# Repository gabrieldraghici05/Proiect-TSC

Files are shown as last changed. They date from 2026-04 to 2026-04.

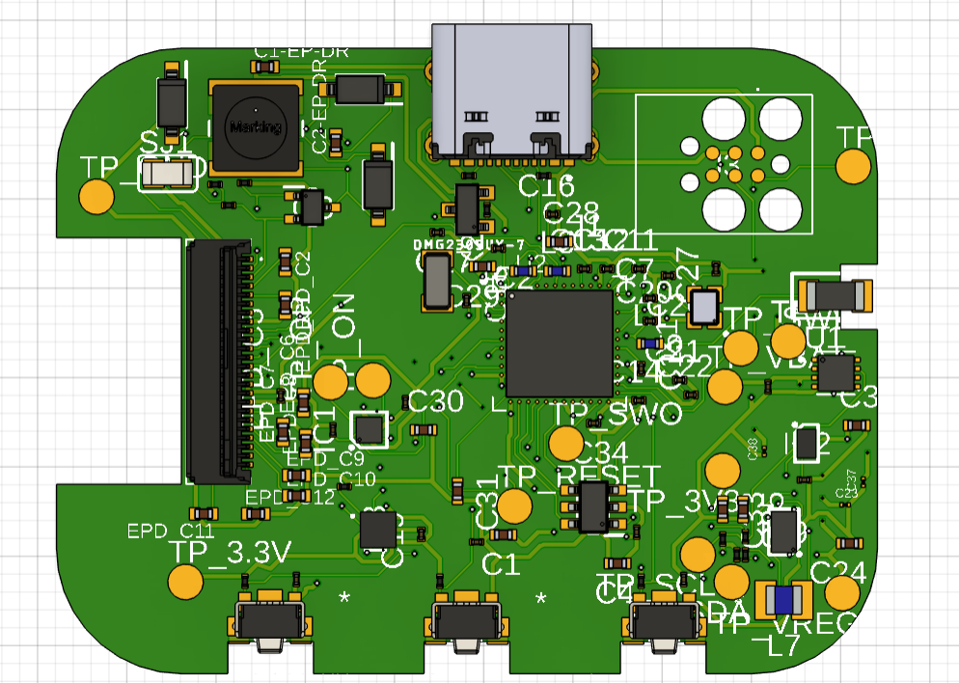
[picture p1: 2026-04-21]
Images/PCB 3D.png

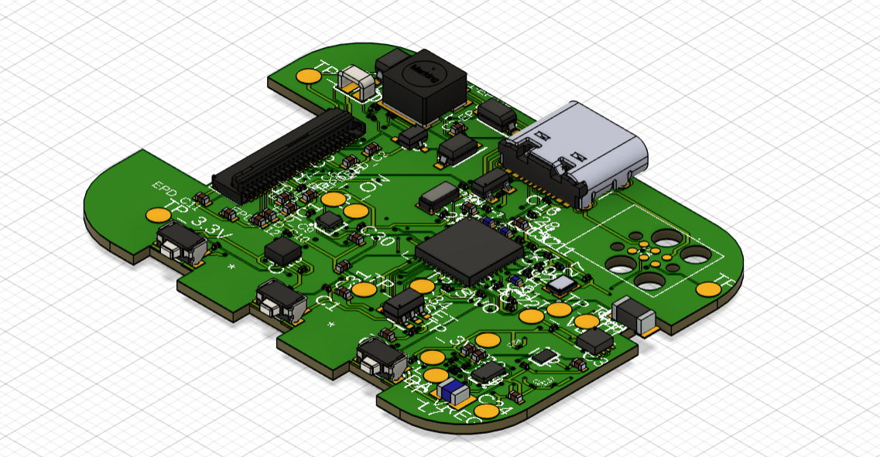
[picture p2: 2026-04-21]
Images/PCB 3D - 2.png

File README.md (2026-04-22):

# Proiect-TSC

## Descriere generală

InkTime este un smartwatch construit în jurul microcontroller-ului nRF52840, utilizând un afișaj E-Paper. Proiectul este dezvoltat în Autodesk Fusion: de la concepția schemelor și rutarea unui PCB pe 4 straturi, până la integrarea mecanică finală în carcasă.

Principalele caracteristici:
- Procesare: nRF52840 (Cortex-M4F) cu conectivitate Bluetooth 5.0 integrată
- Afișaj: Ecran E-Paper (SPI)
- Senzori: Accelerometru BMA423 pentru pedometru și gesturi
- Baterie LiPo cu circuit de încărcare dedicat (BQ25180).
- Regulator DC/DC (RT6160) pentru o tensiune stabilă de 3.3V
- Fuel Gauge (MAX17048) pentru monitorizarea nivelului bateriei
- Driver haptic (DRV2605) pentru feedback
- Conectivitate USB-C pentru încărcare
- 3 butoane fizice pentru interacțiune

---

## Diagrama bloc

```text
                         +-------------------+
                         |    Baterie LiPo   |
                         +--------+----------+
                                  |
                         +--------v----------+
                         |  LiPo Charger     |  <-- USB-C (5V / VBUS)
                         |  BQ25180YBGR      |
                         +--------+----------+
                                  | VBAT (3.7-4.2V)
                         +--------v----------+
                         |  Fuel Gauge       |  <-- I2C --> nRF52840
                         |  MAX17048G+T10    |
                         +--------+----------+
                                  |
                         +--------v----------+
                         |  DC/DC Regulator  |  <-- I2C --> nRF52840
                         |  RT6160AWSC       |
                         +--------+----------+
                                  | 3V3
          +-----------------------+-----------------------+
          |                       |                       |
+---------v---------+   +---------v---------+   +---------v---------+
|   nRF52840 (U1)   |   |  ESD Protection   |   |   Butoane (x3)    |
|   Microcontroller |   |  USBLC6-2SC6Y     |   |   EVP-AKE31A      |
+---------+---------+   +-------------------+   +-------------------+
          |
    +-----+------+------+------+
    |            |      |      |
+---v---+  +----v--+  +-v---+ +-v---------+
| SPI   |  |  I2C  |  | SWD | | GPIO/ANT  |
+---+---+  +---+---+  +-----+ +-----------+
    |          |
+---v---+   +--+--+--+--+
|E-Paper|   | IMU | Haptic|
|Display|   |BMA423|DRV2605|
+-------+   +-------+-----+
```

---
## Bill of Materials (BOM)

| Cantitate | Componenta | Descriere | Referinta | 
|:---:|:---:|:---:|:---:|
| 1 | nRF52840 | Microcontroller ARM Cortex-M4, BT 5.0 | U1 | 
| 1 | BQ25180YBGR | LiPo Charger IC, 8-DSBGA | IC1 | 
| 1 | DRV2605YZFR | Haptic Driver ERM/LRA, 9-BGA | IC2 |
| 1 | BMA423 | IMU Accelerometru triaxial 12-bit | IC3 |
| 1 | MAX17048G+T10 | Fuel Gauge 1-Cell ModelGauge | U3 | 
| 1 | RT6160AWSC | Buck-Boost DC/DC Regulator I2C, 15-WL-CSP | IC9 | 
| 1 | USBLC6-2SC6Y | ESD Protection TVS Diode, SOT-23-6 | D3 | 
| 1 | KH-TYPE-C-16P | Conector USB-C 16 pini | J4 |
| 1 | 503480-2400 | Conector FPC/FFC 0.5mm 24 circuite | J1 | 
| 1 | DMG2305UX-7 | P-Channel MOSFET 20V/4.2A SOT-23 | Q2 | 
| 1 | SI1308EDL-T1-GE3 | N-Channel MOSFET 30V/1.5A SC-70 | Q3 | 
| 3 | MBR0530 | Dioda Schottky 30V/500mA SOD-123 | D1, D2, D5 | 
| 3 | EVP-AKE31A | Buton tactil SMD ultra-subtire | SW_DN, SW_ENT, SW_UP | 
| 1 | 2450AT18B100E | Antena 2.45GHz SMD | ANT1 | 
| 1 | FTC252012SR47MBCA | Inductor SMD 0.47uH 2016 | L7 | 
| 1 | 744043680 | Inductor SMD 68uH WE-TPC | L5 |
| 1 | TC2030-IDC | Conector Tag-Connect 6 pini SWD | J2 |
| 1 | X1 (32MHz) | Crystal 32MHz 2016 SMD | X1 |
| 1 | X2 (32.768kHz) | Crystal 32.768kHz 3215 SMD | X2 | 
| ~50 | Condensatoare SMD | 0201/0402, diverse valori (1pF - 22uF) | Cx | 
| ~15 | Rezistoare SMD | 0201, diverse valori (2.2Ω - 10kΩ) | Rx |
| ~4 | Inductoare SMD | 0402, diverse valori (3.9nH - 15nH, 10uH) | Lx |
| 14 | Test Pad TP20R | Test pad-uri SMD 2mm | TP_* |
| 1 | Solder Jumper SJ | Jumper SMD | SJ1 |

---

## Funcționalitate hardware

#### Componente și roluri
Sistemul este coordonat de nRF52840, care gestionează atât logica internă, stările de sleep pentru economisirea energiei, cât și comunicarea Bluetooth.

* Alimentare și Power Management: Bateria Li-Po este conectată direct la test pad-urile plăcii pentru a economisi spațiu pe verticală. Încărcarea este gestionată de BQ25180. Tensiunea bateriei este monitorizată precis de Fuel Gauge-ul MAX17048, iar alimentarea componentelor logice la 3.3V este asigurată de convertorul DC/DC RT6160 (ales în detrimentul unui LDO pentru un randament energetic superior).

* Interfața cu utilizatorul: Afișajul E-Paper este controlat prin SPI pentru o viteză mare de transfer, consumând energie doar la actualizarea imaginii. Input-ul se face prin 3 butoane tactile cu debouncing software, iar feedback-ul este asigurat de driverul haptic DRV2605 conectat la un actuator de tip shaker.

* Senzori: Accelerometrul BMA423 este legat pe magistrala I2C și este folosit pentru funcții precum ridicarea mâinii pentru aprindere (wake-on-wrist).

#### Interfețe de comunicație
* I2C: LiPo Charger, DC/DC, IMU, Fuel Gauge, Haptic Driver. (Folosește rezistențe de pull-up externe pentru stabilitate).

* SPI: E-Paper Display Connector (viteză mare de transmisie a datelor grafice).

---

## Pinii nRF52840

| Pin nRF52840 | Semnal | Modul conectat | Interfata | Descriere |
| :--- | :--- | :--- | :--- | :--- |
| P0.02/AIN0 | SCK | E-Paper Display | SPI | Clock serial SPI |
| P0.03/AIN1 | MOSI | E-Paper Display | SPI | Date catre display (Master Out Slave In) |
| P0.05/AIN3 | CS | E-Paper Display | SPI | Chip Select display |
| P0.15 | EPD_RST | E-Paper Display | GPIO | Reset display |
| P0.16 | EPD_DC | E-Paper Display | GPIO | Data/Command select |
| P0.17 | EPD_BUSY | E-Paper Display | GPIO | Stare ocupata display |
| P0.06 | SCL | IMU, LiPo Charger, DC/DC, Fuel Gauge, Haptic | I2C | Clock linie I2C |
| P0.07 | SDA | IMU, LiPo Charger, DC/DC, Fuel Gauge, Haptic | I2C | Date linie I2C |
| P0.08 | IMU_INT2 | BMA423 | GPIO | Intrerupere 2 accelerometru |
| P1.08 | IMU_INT1 | BMA423 | GPIO | Intrerupere 1 accelerometru |
| P0.10/NFC2 | FUELGAUGE_ALT | MAX17048 | GPIO | Alarma nivel scazut baterie |
| P0.11 | CHARGER_PG | BQ25180 | GPIO | Semnal Power Good charger |
| P0.12 | HAPTIC_EN | DRV2605 | GPIO | Enable driver haptic |
| P0.13 | BTN_UP | SW_UP | GPIO | Buton sus |
| P0.14 | BTN_ENT | SW_ENT | GPIO | Buton enter/confirmare |
| P1.02 | BTN_DN | SW_DN | GPIO | Buton jos |
| D+ / D- | USB_DP / DM | USB-C / ESD | USB | Date USB diferentiale |
| VBUS | 5V USB | LiPo Charger | - | Alimentare 5V din USB |
| SWDIO / CLK | SWDIO / CLK| TC2030-IDC (J2) | SWD | Date programare/debug |
| SWO | SWO | TC2030-IDC (J2) | SWD | Trace output |
| P0.18/RESET | RESET | TC2030-IDC (J2) | GPIO | Reset hardware microcontroller |
| ANT | RF | 2450AT18B100E | RF | Antena Bluetooth 2.4GHz |
| XC1, XC2 | XTAL_32M | X1 (32 MHz) | Clock | Sursa de ceas principala |
| XL1, XL2 | XTAL_32K | X2 (32.768 kHz) | Clock | Sursa de ceas RTC (low power) |

---
## Design PCB si Modelare Mecanică 3D

### Stackup PCB — 4 straturi
Placa a fost realizată pe 4 straturi pentru a asigura o integritate a semnalului excelentă și o rutare compactă:

* Top (L1): Rutare semnal + componente SMD.

* L2: Plan de masă (GND solid) care oferă un return path scurt pentru toate semnalele.

* L3: Rutare secundară — acest strat a fost utilizat în principal pentru rezolvarea manuală a Airwire-urilor rămase în urma procesului de autorutare, asigurând finalizarea tuturor conexiunilor complexe.

* Bottom (L4): Rutare semnal secundar.

### Decizii de design notabile
* Decupaj Antenă (RF): Antena ceramică este poziționată pe marginea plăcii. Sub aceasta s-a realizat un decupaj complet al substratului pe toate planurile (ground clearance) pentru performanță radio optimă.

* Via-in-Pad: Pentru componentele BGA dense, a fost utilizată tehnologia via-in-pad pentru a salva spațiu, rutând semnalele direct din pad-uri.

* Pad-uri de Test: Au fost adăugate 14 test pad-uri pentru semnalele vitale (3V3, VBAT, SWD, I2C), pentru lipirea directă a bateriei.

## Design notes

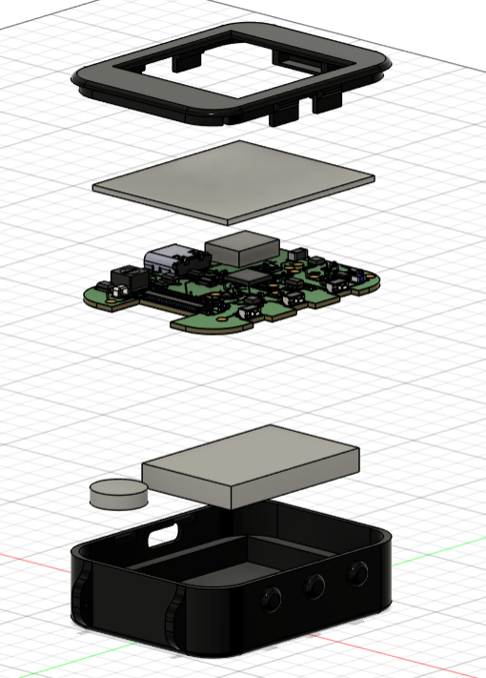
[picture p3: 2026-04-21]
Images/Watch Exploded.png

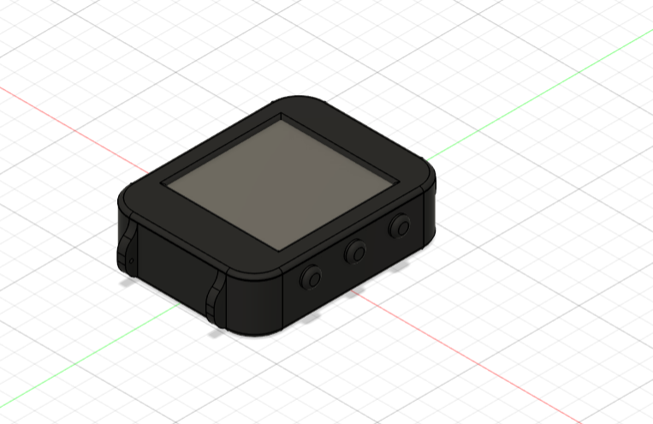
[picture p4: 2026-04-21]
Images/Watch.png

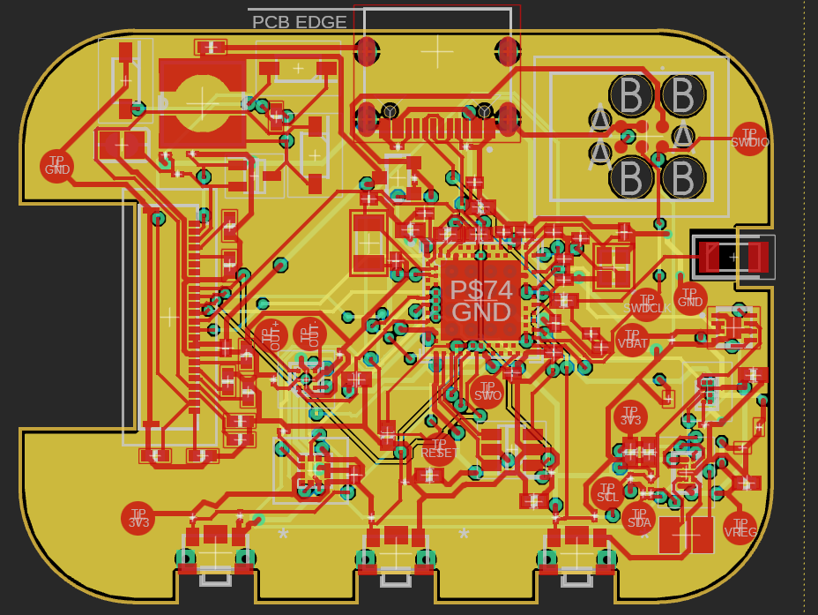
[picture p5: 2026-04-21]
Images/PCB 2D.png

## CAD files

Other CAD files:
Mechanical/Watch.f3z

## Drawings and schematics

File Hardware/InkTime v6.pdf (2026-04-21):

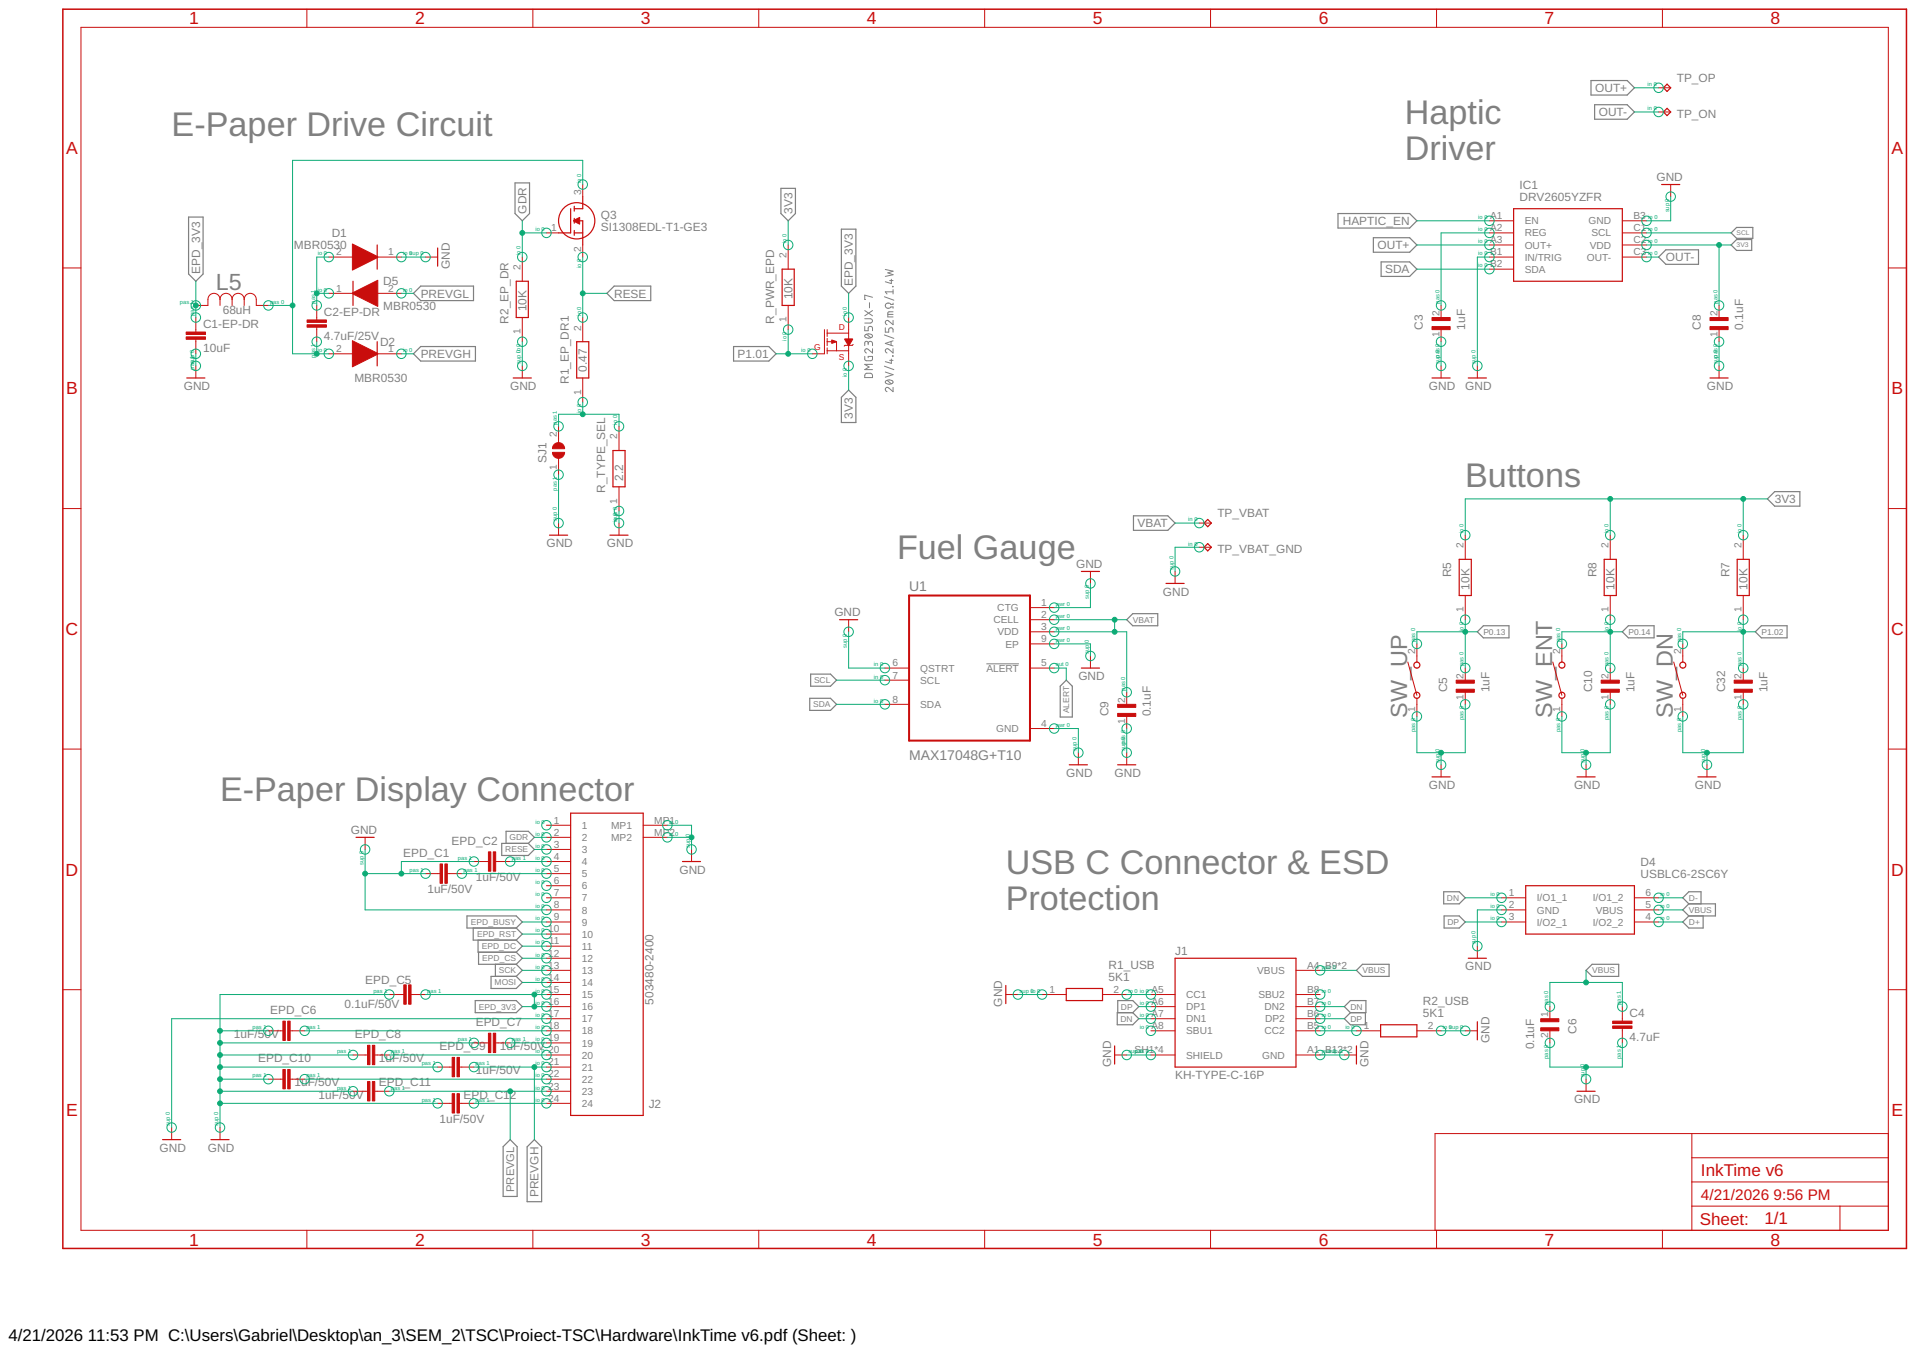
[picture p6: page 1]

E-Paper Drive Circuit Driver | TP_OP

pas 1 | EPD_C7 18 pas 1 io 0
1uF/50V | EPD_C8 pas 1 | pas 1 io 0 19
EPD_C10 | 1uF/50V pas 1 | 21 pas 1 io 0
pas 1 | pas 1 | 1uF/50V | 22 io 0

pas 1 | EPD_C9 pas 1 | 1uF/50V 20 io 0

1uF/50V pas 1 | EPD_C11 pas 1 | 23 io 0
1uF/50V | pas 1 | EPD_C12 pas 1 | | io 0 24

4/21/2026 11:53 PM C:\Users\Gabriel\Desktop\an_3\SEM_2\TSC\Proiect-TSC\Hardware\InkTime v6.pdf (Sheet: )

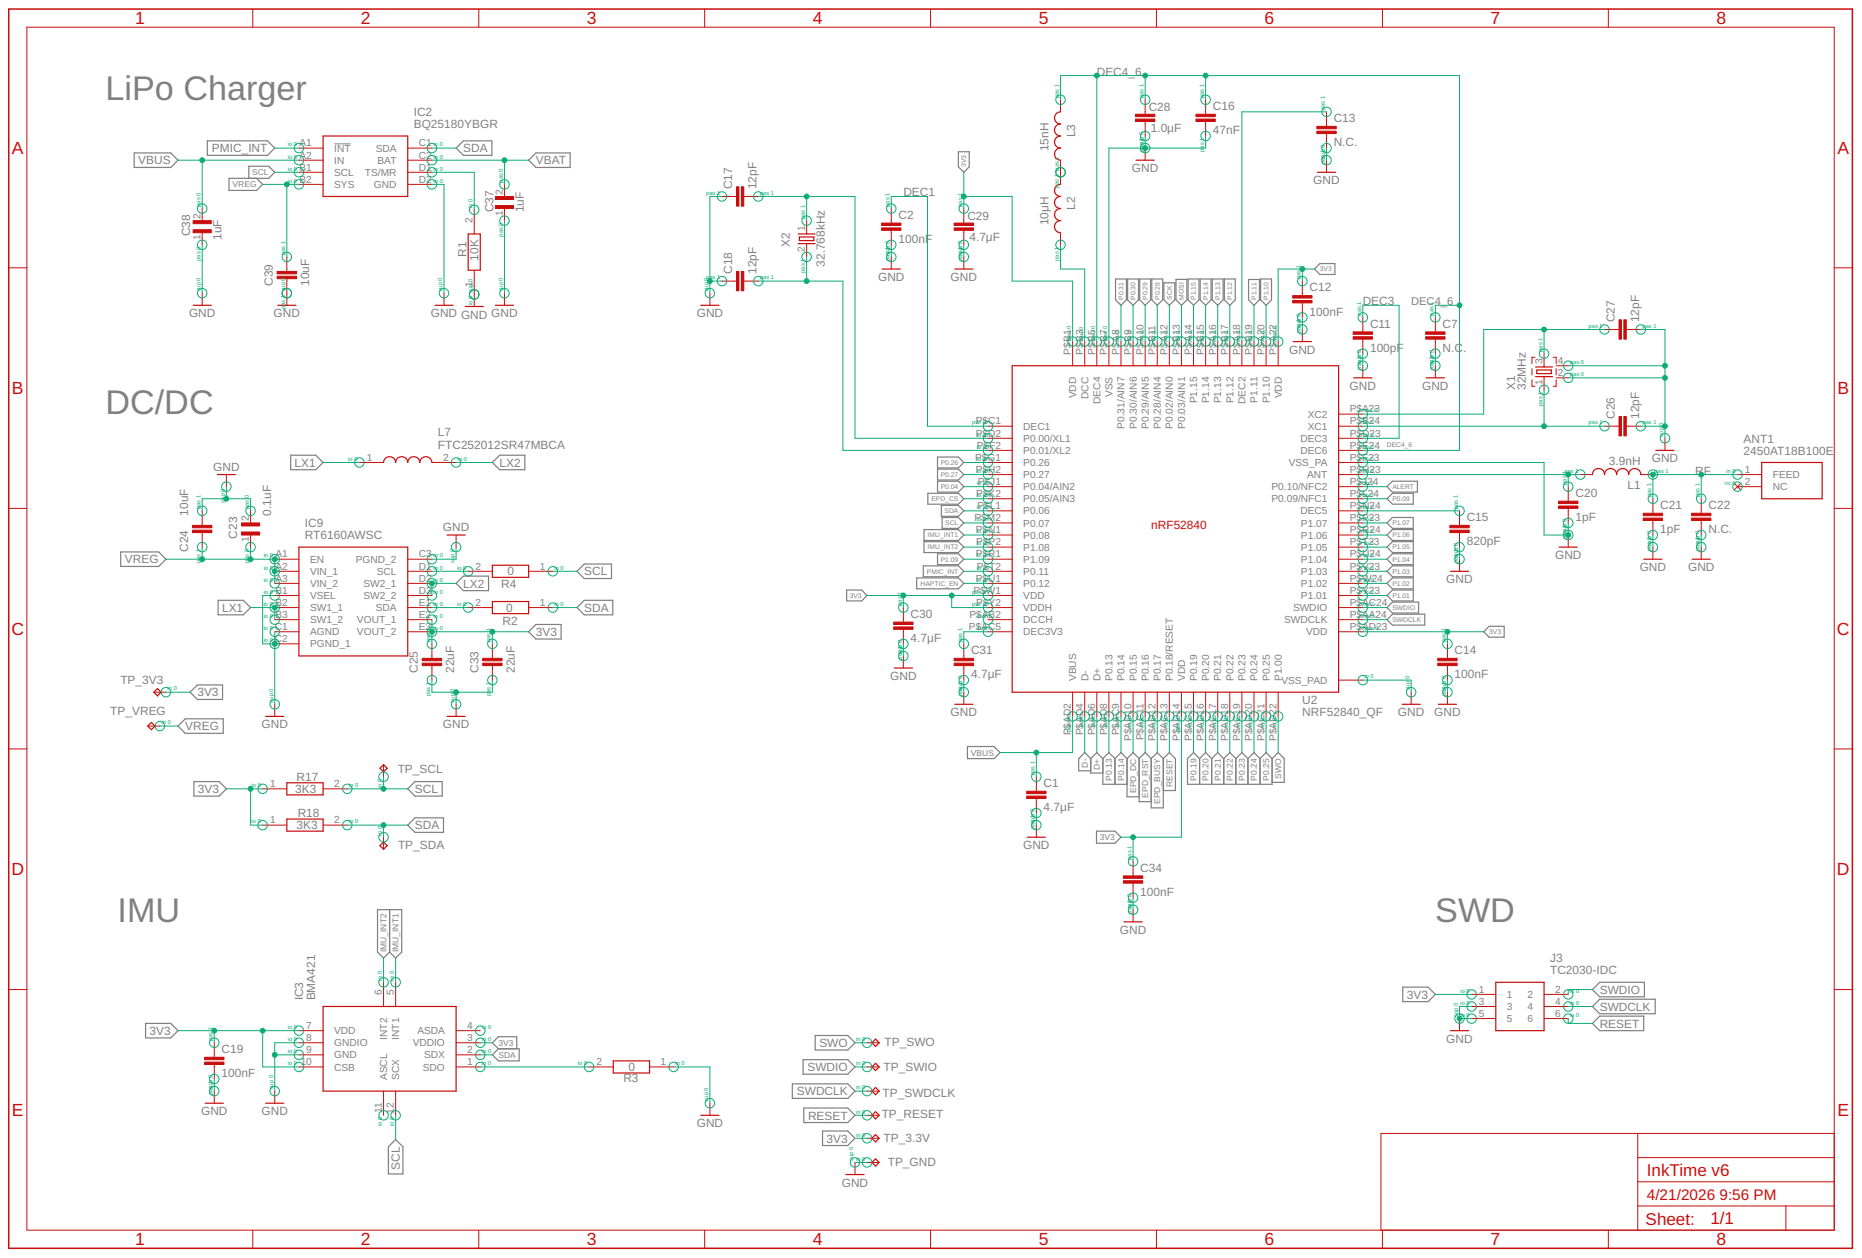
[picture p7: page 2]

pas 1 pas 1

1uF GND GND GND GND GND

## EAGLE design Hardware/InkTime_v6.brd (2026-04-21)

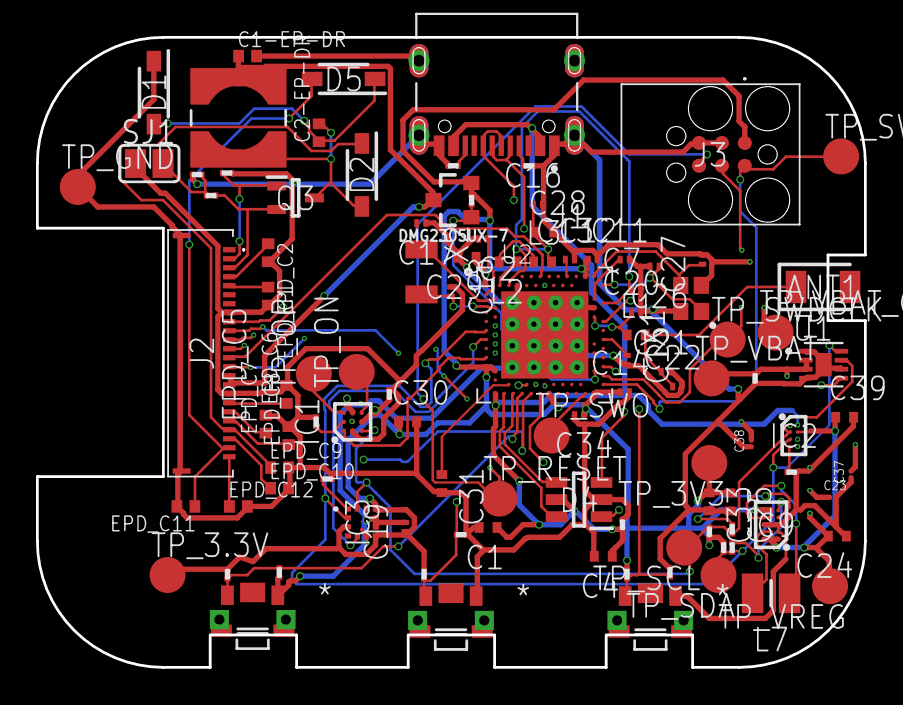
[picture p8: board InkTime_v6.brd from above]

Board: 4 copper layers, 46.0 x 35.0 mm, 105 parts (0 on the bottom side), 70 nets.

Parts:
ANT1: 2450AT18B100E; 2450AT18B100E_ANTC3216X140N
C1, C29, C30, C31: 4.7μF; NORDIC_NRF_3_RESC0402_L
C1-EP-DR: 10uF; PERFECT_0402_0402
C2, C12, C14, C19, C34: 100nF; NORDIC_NRF_3_RESC0201_L
C2-EP-DR: 4.7uF/25V; PERFECT_0402_0402
C3, C5, C10, C32: 1uF; GRM011R60J152KE01L_1_0201
C4: 4.7uF; NORDIC_NRF_3_RESC0402_L
C6, C8, C9: 0.1uF; GRM011R60J152KE01L_1_0201
C7, C13, C22: N.C.; NORDIC_NRF_3_RESC0201_L
C11: 100pF; NORDIC_NRF_3_RESC0201_L
C15: 820pF; NORDIC_NRF_3_RESC0201_L
C16: 47nF; NORDIC_NRF_3_RESC0201_L
C17, C18, C26, C27: 12pF; NORDIC_NRF_3_RESC0201_L
C20, C21: 1pF; NORDIC_NRF_3_RESC0201_L
C23: 0.1uF; GRM011R60J152KE01L_2_CAPC0201X13N
C24, C39: 10uF; NORDIC_NRF_3_RESC0402_L
C25, C33: 22uF; NORDIC_NRF_3_RESC0402_L
C28: 1.0μF; NORDIC_NRF_3_RESC0402_L
C37, C38: 1uF; GRM011R60J152KE01L_2_CAPC0201X13N
D1, D2, D5: MBR0530; ESP32_C6_LIBRARY_5_SOD3716X135N
D4: USBLC6-2SC6Y; ESP32_C6_LIBRARY_3_SOT95P280X145-6N
DMG2305UX-7: 20V/4.2A/52mΩ/1.4W; ESP32_C6_LIBRARY_4_ESP32_C6_LIBRARY_4_ESP32_C6_LIBRARY_4_ES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
EPD_C1, EPD_C2, EPD_C6, EPD_C7, EPD_C8, EPD_C9, EPD_C10, EPD_C11, EPD_C12: 1uF/50V; PERFECT_0402_0402
EPD_C5: 0.1uF/50V; NORDIC_NRF_3_RESC0201_L
IC1: DRV2605YZFR; DRV2605YZFR_BGA9C50P3X3_144X144X62
IC2: BQ25180YBGR; BQ25180YBGR_BGA8C40P2X4_100X155X50
IC3: BMA421; BMA423_BMA423
IC9: RT6160AWSC; RT6160AWSC_BGA15C40P3X5_140X230X60
J1: KH-TYPE-C-16P; KH-TYPE-C-16P_KINGHELM_KH-TYPE-C-16P
J2: 503480-2400; 503480-2400_5034802400
J3: TC2030-IDC; TC2030-IDC_TC2030IDC
L1: 3.9nH; NORDIC_NRF_2_RESC0402_L
L2: 10μH; NORDIC_NRF_2_RESC0402_L
L3: 15nH; NORDIC_NRF_2_RESC0402_L
L5: 68uH; ESP32_C6_LIBRARY_2_IND_4828-WE-TPC_WRE
L7: FTC252012SR47MBCA; MLP2016SR47MT0S1_INDC2016X100N
Q3: SI1308EDL-T1-GE3; ESP32_C6_LIBRARY_6_SOT65P210X110-3N
R1, R2_EP_DR, R5, R7, R8: 10K; CPF0201D7K68C1_0201
R1_EP_DR1: 0.47; CPF0201D7K68C1_0201
R1_USB, R2_USB: 5K1; CPF0201D7K68C1_0201
R2, R3, R4: 0; CPF0201D7K68C1_0201
R17, R18: 3K3; ERA-1AEB3401C_0201
R_PWR_EPD: 10K; CPF0201D7K68C1_0201
R_TYPE_SEL: 2.2; CPF0201D7K68C1_0201
SJ1: ESP32_C6_LIBRARY_7_JUMPER_SJ
SW_DN: 2025-10-22_07-23-44_LIBRARY_EVP-AKE31ASW_EVP-AKE3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; 2025-10-22_07-23-44_LIBRARY_SW_EVP-AKE31A_PAN
SW_ENT: 2025-10-22_07-23-44_LIBRARY_EVP-AKE31ASW_EVP-AKE3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; 2025-10-22_07-23-44_LIBRARY_SW_EVP-AKE31A_PAN
SW_UP: 2025-10-22_07-23-44_LIBRARY_EVP-AKE31ASW_EVP-AKE3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; 2025-10-22_07-23-44_LIBRARY_SW_EVP-AKE31A_PAN
TP_3.3V, TP_3V3: HECTOR_WATCH_1_TPTP20R; HECTOR_WATCH_1_TP20R
TP_GND: HECTOR_WATCH_1_TPTP20R; HECTOR_WATCH_1_TP20R
TP_ON: HECTOR_WATCH_1_TPTP20R; HECTOR_WATCH_1_TP20R
TP_OP: HECTOR_WATCH_1_TPTP20R; HECTOR_WATCH_1_TP20R
TP_RESET: HECTOR_WATCH_1_TPTP20R; HECTOR_WATCH_1_TP20R
TP_SCL: HECTOR_WATCH_1_TPTP20R; HECTOR_WATCH_1_TP20R
TP_SDA: HECTOR_WATCH_1_TPTP20R; HECTOR_WATCH_1_TP20R
TP_SWDCLK: HECTOR_WATCH_1_TPTP20R; HECTOR_WATCH_1_TP20R
TP_SWIO: HECTOR_WATCH_1_TPTP20R; HECTOR_WATCH_1_TP20R
TP_SWO: HECTOR_WATCH_1_TPTP20R; HECTOR_WATCH_1_TP20R
TP_VBAT: HECTOR_WATCH_1_TPTP20R; HECTOR_WATCH_1_TP20R
TP_VBAT_GND: HECTOR_WATCH_1_TPTP20R; HECTOR_WATCH_1_TP20R
TP_VREG: HECTOR_WATCH_1_TPTP20R; HECTOR_WATCH_1_TP20R
U1: MAX17048G+T10; ESP32_C6_LIBRARY_SON50P200X200X80-9N
U2: NRF52840_QF; NORDIC_NRF_4_AQFN50P700X700X85_HS-74N
X1: 32MHz; NORDIC_NRF_BT-XTAL_2016_N
X2: 32.768kHz; NORDIC_NRF_1_XTAL_3215_N

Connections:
3V3: C8.2, C12.1, C14.1, C19.1, C25.1, C29.1, C30.1, C33.1, C34.1, DMG2305UX-7.2, IC1.C2, IC3.3, IC3.7, IC3.10, IC9.E2, IC9.E3, J3.1, R5.2, R7.2, R8.2, R17.1, R18.1, R_PWR_EPD.2, TP_3.3V.TP, TP_3V3.TP, U2.P$A22, U2.P$AD14, U2.P$AD23, U2.P$B1, U2.P$W1, U2.P$Y2
ALERT: U1.5, U2.P$J24
D+: D4.4, U2.P$AD6
D-: D4.6, U2.P$AD4
DEC1: C2.1, U2.P$C1
DEC3: C11.1, U2.P$D23
DEC4_6: C7.1, C16.1, C28.1, L3.2, U2.P$B5, U2.P$E24
DN: D4.1, J1.A7, J1.B7
DP: D4.3, J1.A6, J1.B6
EPD_3V3: C1-EP-DR.1, DMG2305UX-7.3, EPD_C5.2, J2.15, J2.16, L5.2
EPD_BUSY: J2.9, U2.P$AD12
EPD_CS: J2.12, U2.P$K2
EPD_DC: J2.11, U2.P$AD10
EPD_RST: J2.10, U2.P$AC11
GDR: J2.2, Q3.1, R2_EP_DR.2
GND: C1.2, C1-EP-DR.2, C2.2, C3.1, C4.2, C5.1, C6.2, C7.2, C8.1, C9.1, C10.1, C11.2, C12.2, C13.2, C14.2, C15.2, C16.2, C17.1, C18.1, C19.2, C20.2, C21.2, C22.2, C23.2, C24.1, C25.2, C26.2, C27.2, C28.2, C29.2, C30.2, C31.2, C32.1, C33.2, C34.2, C37.1, C38.1, C39.2, D1.1, D4.2, EPD_C1.2, EPD_C2.2, EPD_C5.1, EPD_C6.2, EPD_C7.2, EPD_C8.2, EPD_C9.2, EPD_C10.2, EPD_C11.2, EPD_C12.2, IC1.B1, IC1.B3, IC2.D2, IC3.8, IC3.9, IC9.B1, IC9.C1, IC9.C2, IC9.C3, J1.A1_B12, J1.A12_B1, J1.SH1, J1.SH2, J1.SH3, J1.SH4, J2.8, J2.17, J2.MP1, J2.MP2, J3.3, J3.5, R1.1, R1_USB.1, R2_EP_DR.1, R2_USB.2, R3.1, R_TYPE_SEL.1, SJ1.1, SW_DN.1, SW_ENT.1, SW_UP.1, TP_GND.TP, TP_VBAT_GND.TP, U1.1, U1.4, U1.6, U1.9, U2.P$74, U2.P$75, U2.P$76, U2.P$77, U2.P$78, U2.P$79, U2.P$80, U2.P$81, U2.P$82, U2.P$83, U2.P$84, U2.P$85, U2.P$86, U2.P$87, U2.P$88, U2.P$89, U2.P$90, U2.P$B7, U2.P$F23, X1.2, X1.4
HAPTIC_EN: IC1.A1, U2.P$U1
IMU_INT1: IC3.5, U2.P$N1
IMU_INT2: IC3.6, U2.P$P2
LX1: IC9.B2, IC9.B3, L7.1
LX2: IC9.D2, IC9.D3, L7.2
MOSI: J2.14, U2.P$B13
unnamed: C2-EP-DR.1, D1.2, D5.1
unnamed: C2-EP-DR.2, D2.2, L5.1, Q3.3
unnamed: R1_EP_DR1.1, R_TYPE_SEL.2, SJ1.2
unnamed: IC2.D1, R1.2
unnamed: C3.2, IC1.A2
unnamed: J1.B5, R2_USB.1
unnamed: EPD_C6.1, J2.18
unnamed: EPD_C7.1, J2.19
unnamed: EPD_C2.1, J2.4
unnamed: J1.A5, R1_USB.2
unnamed: EPD_C1.1, J2.5
unnamed: EPD_C8.1, J2.20
unnamed: EPD_C10.1, J2.22
unnamed: EPD_C12.1, J2.24
unnamed: IC9.D1, R4.2
unnamed: IC9.E1, R2.2
unnamed: IC3.1, R3.2
unnamed: C31.1, U2.P$AC5
unnamed: C17.2, U2.P$D2, X2.1
unnamed: C18.2, U2.P$F2, X2.2
unnamed: L2.1, U2.P$B3
unnamed: L2.2, L3.1
unnamed: C13.1, U2.P$A18
unnamed: C15.1, U2.P$N24
unnamed: C20.1, L1.1, U2.P$H23
unnamed: C26.1, U2.P$B24, X1.1
unnamed: C27.1, U2.P$A23, X1.3
OUT+: IC1.A3, TP_OP.TP
OUT-: IC1.C3, TP_ON.TP
P0.13: C5.2, R5.1, SW_UP.2, U2.P$AD8
P0.14: C10.2, R8.1, SW_ENT.2, U2.P$AC9
P1.01: DMG2305UX-7.1, R_PWR_EPD.1, U2.P$Y23
P1.02: C32.2, R7.1, SW_DN.2, U2.P$W24
PMIC_INT: IC2.A1, U2.P$T2
PREVGH: D2.1, EPD_C9.1, J2.21
PREVGL: D5.2, EPD_C11.1, J2.23
RESE: J2.3, Q3.2, R1_EP_DR1.2
RESET: J3.6, TP_RESET.TP, U2.P$AC13
RF: ANT1.1, C21.1, C22.1, L1.2
SCK: J2.13, U2.P$A12
SCL: IC1.C1, IC2.B1, IC3.12, R4.1, R17.2, TP_SCL.TP, U1.7, U2.P$M2
SDA: IC1.B2, IC2.C1, IC3.2, R2.1, R18.2, TP_SDA.TP, U1.8, U2.P$L1
SWDCLK: J3.4, TP_SWDCLK.TP, U2.P$AA24
SWDIO: J3.2, TP_SWIO.TP, U2.P$AC24
SWO: TP_SWO.TP, U2.P$AD22
VBAT: C9.2, C37.2, IC2.C2, TP_VBAT.TP, U1.2, U1.3
VBUS: C1.1, C4.1, C6.1, C38.2, D4.5, IC2.A2, J1.A4_B9, J1.A9_B4, U2.P$AD2
VREG: C23.1, C24.2, C39.1, IC2.B2, IC9.A1, IC9.A2, IC9.A3, TP_VREG.TP

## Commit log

2026-04-10 fisiere hardware
    [InkTime v6.brd, InkTime_v6.sch]
2026-04-21 PDF Schematic
2026-04-21 gerbers final
2026-04-21 BOM si CPL actualizate
2026-04-21 PCB finalizat
    [InkTime_v6.brd]
2026-04-21 fisier Fusion360
    [Watch.f3z]

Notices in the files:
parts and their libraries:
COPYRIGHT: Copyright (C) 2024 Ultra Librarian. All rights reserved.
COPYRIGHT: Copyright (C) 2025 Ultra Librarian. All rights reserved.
